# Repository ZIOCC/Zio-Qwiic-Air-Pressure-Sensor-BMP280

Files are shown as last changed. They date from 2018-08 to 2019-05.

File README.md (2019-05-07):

# Zio Qwiic Air Pressure Sensor BMP280

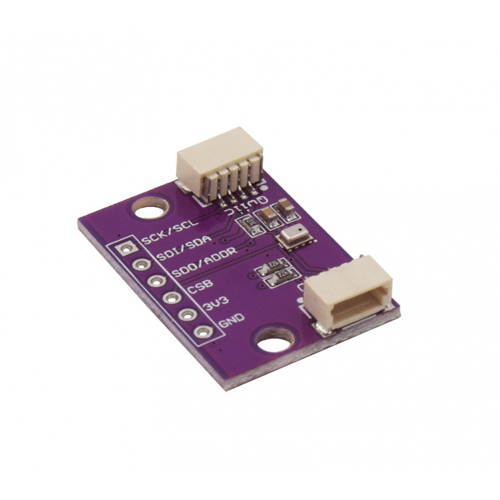
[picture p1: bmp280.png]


> This product can be available for purchase [here](https://www.smart-prototyping.com/Zio-Qwiic-Air-Pressure-Sensor-BMP280).

##### Description

This little board features a high precision BMP280 Barometric Pressure and Altitude Sensor by Bosch. The sensor is not only capable of sensing pressure and altitude but it also environmental temperature, almost all the data you need around atmospheric conditions.

The sensor is one of the best low-cost solutions when it comes to take precise environmental data. The barometric pressure has a ±1.0 hPa absolute accuracy, on pressures from 200 hPa to 11hPa. Temperature measurements are pretty accurate also, with a ±1.0°C accuracy on temperatures between -40 and 85°C.

As the altitude increases, the atmospheric pressure decreases - and due to the sensor high accuracy on taking pressure measurements - the altitude can also be calculated. With a  ±1 meter precision on altitude sensing. 

Great sensor right? As a member of our Qwiic family, the board incorporates the Qwiic connector for easy wiring to use I2C interface. But this great little sensor can use either I2C or SPI so we made it pretty accessible to switch to SPI. Simply solder the header pins provided if you want to go for it!

##### Specification

* Operation Voltage: 3.3V
* Current Consumption: 2.7μA
* Barometric Pressure Measure
  * Range: 300 – 1100 hPa
  * Accuracy: ±1.0 hPa
* Temperature Measurement
  * Range: -40 to 85
  * Accuracy: ±1
* Interface: I2C and SPI
* Port: I2C (selectable address at 0x77(default) and 0x76)
* Dimensions: 16.5mm x 25.3mm
* Weight: 1.4g

##### Links

* [Eagle File & Schematic](https://github.com/ZIOCC/Zio-Qwiic-Air-Pressure-Sensor-BMP280)
* [BMP280 library Link](https://github.com/adafruit/Adafruit_BMP280_Library)
* [BMP280 Datasheet](https://cdn-shop.adafruit.com/datasheets/BST-BMP280-DS001-11.pdf)

> ###### About Zio
> Zio is a new line of open sourced, compact, and grid layout boards, fully integrated for Arduino and Qwiic ecosystem. Designed ideally for wearables, robotics, small-space limitations or other on the go projects. Check out other awesome Zio products [here](https://www.smart-prototyping.com/Zio).

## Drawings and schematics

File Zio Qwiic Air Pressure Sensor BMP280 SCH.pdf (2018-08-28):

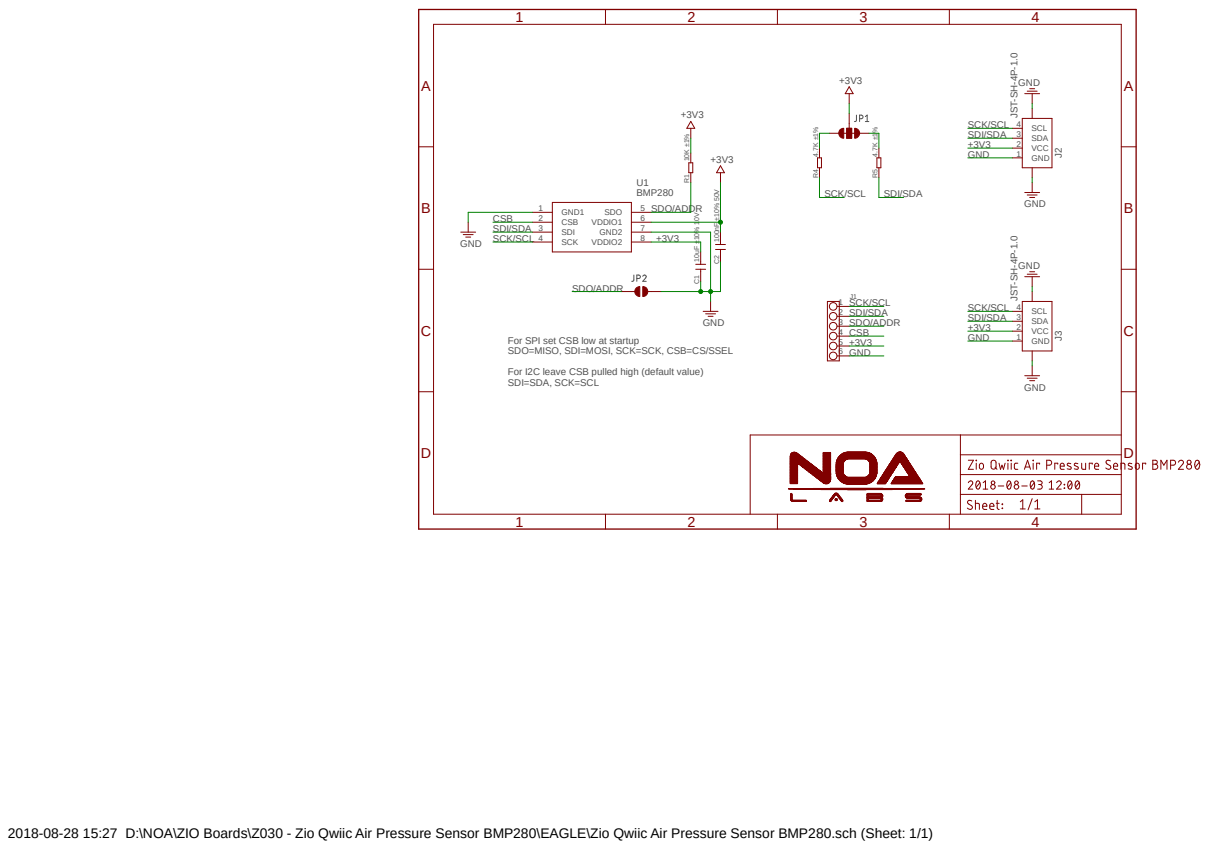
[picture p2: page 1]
BMP280; GND; GND 4.7K ±1%; 4.7K ±1% 10uF ±10% ¹⁰V; 100nF ±10% ⁵⁰V GND; U1 GND1 1; CSB 2; SDI 3; SCK 4; SDO; 5 VDDIO1; 6 GND2; 7 VDDIO2; GND 1; VCC 2; SDA 3; SCL 4; J3 JST⁻SH⁻⁴P⁻¹.0; J2 JST⁻SH⁻⁴P⁻¹.0 R⁴; CSB; SDI/SDA; SCK/SCL; SDO/ADDR

For SPI set CSB low at startup
SDO=MISO, SDI=MOSI, SCK=SCK, CSB=CS/SSEL
For I2C leave CSB pulled high (default value)
SDI=SDA, SCK=SCL

2018-08-28 15:27 D:\NOA\ZIO Boards\Z030 - Zio Qwiic Air Pressure Sensor BMP280\EAGLE\Zio Qwiic Air Pressure Sensor BMP280.sch (Sheet: 1/1)

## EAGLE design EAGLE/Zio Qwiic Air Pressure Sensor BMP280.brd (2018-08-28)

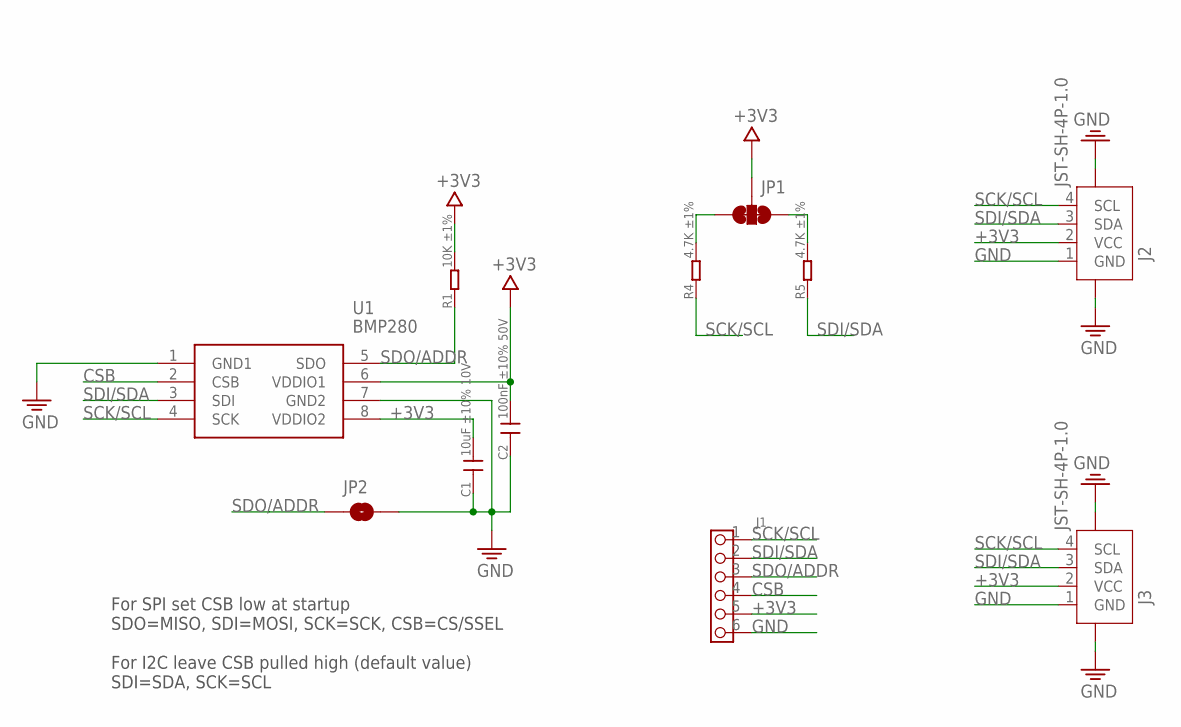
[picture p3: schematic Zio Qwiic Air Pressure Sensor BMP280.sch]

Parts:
C1: 10uF ±10% 10V; C0603
C2: 100nF ±10% 50V; C0603
J1: HEADER-6P-60/35MIL; 6P-2.54-60/35MIL
J2, J3: JST-SH-4P-1.0; JST-SH-4P
JP1: SMT-JUMPER_3_2-NC_TRACE
JP2: JUMPER-SMT_2_NC_PASTE_NOCREM; SMT-JUMPER_2_NC_PASTE_SILK_NOCREM
R1: 10K ±1%; R0603
R4, R5: 4.7K ±1%; R0603
U1: BMP280; 8-PIN-METAL-LID-LGA

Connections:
+3V3: C1.2, C2.2, J1.5, J2.2 (VCC), J3.2 (VCC), JP1.2, R1.2, U1.6 (VDDIO1), U1.8 (VDDIO2)
CSB: J1.4, U1.2 (CSB)
GND: C1.1, C2.1, J1.6, J2.1 (GND), J2.NC1 (5), J2.NC2 (6), J3.1 (GND), J3.NC1 (5), J3.NC2 (6), JP2.2, U1.1 (GND1), U1.7 (GND2)
unnamed: JP1.3, R4.2
unnamed: JP1.1, R5.2
SCK/SCL: J1.1, J2.4 (SCL), J3.4 (SCL), R4.1, U1.4 (SCK)
SDI/SDA: J1.2, J2.3 (SDA), J3.3 (SDA), R5.1, U1.3 (SDI)
SDO/ADDR: J1.3, JP2.1, R1.1, U1.5 (SDO)

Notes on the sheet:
For SPI set CSB low at startup SDO=MISO, SDI=MOSI, SCK=SCK, CSB=CS/SSEL For I2C leave CSB pulled high (default value) SDI=SDA, SCK=SCL

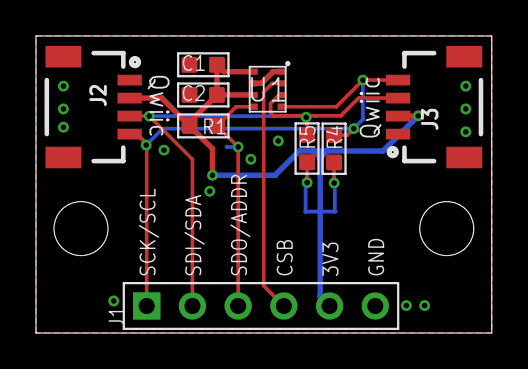
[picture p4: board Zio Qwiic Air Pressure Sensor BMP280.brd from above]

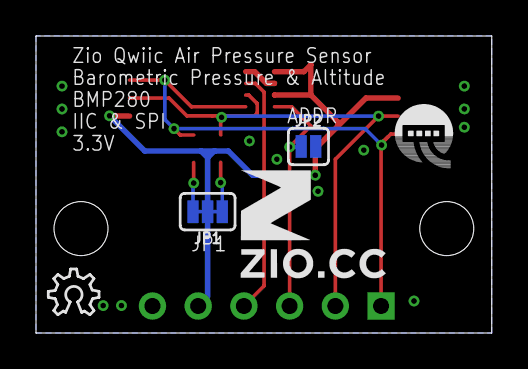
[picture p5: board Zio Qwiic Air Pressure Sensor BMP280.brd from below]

Board: 2 copper layers, 25.3 x 16.5 mm, 14 parts (5 on the bottom side), 8 nets.

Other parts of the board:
U$4: 6MM
U$5: QWIIC-LOGO-BASIC
U$6: OSHW_6X100_NOTEXT
